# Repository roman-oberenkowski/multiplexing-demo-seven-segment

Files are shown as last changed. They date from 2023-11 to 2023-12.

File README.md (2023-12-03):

# Multiplexing demo - 7 segment display
Attiny2313 based educational tool to explain multiplexing effect of seven segment display by slowing down the process.
+ Precompilled HEX file available in 'releases'.
+ Schematic and Kicad project inside 'Schematic' directory.
+ Makefile inside Release directory (Note: built using NixOS, remove/change the compile workaround in Makefile if needed). Makefile generated by Eclipse and AVR plugin.
+ Press (or hold) up/down buttons to increase/decrease refresh frequency (between 1 and 64 Hz).
+ After change display shows current refresh frequency for some time.
+ Power by 9V battery or directly connect 5V to MicroUSB port.
+ Third and fourth digits are flipped to use dots as separator.
+ Includes 3D printable case for 5x7cm prototype boards.
+ Video demo: [Link](https://mega.nz/file/VVUVSJKa#2tisywkgibCrWytnNKbrjdRLIr3S0MkWB7HTtdX4rLc) (Warning: Flashing lights)
## Pics
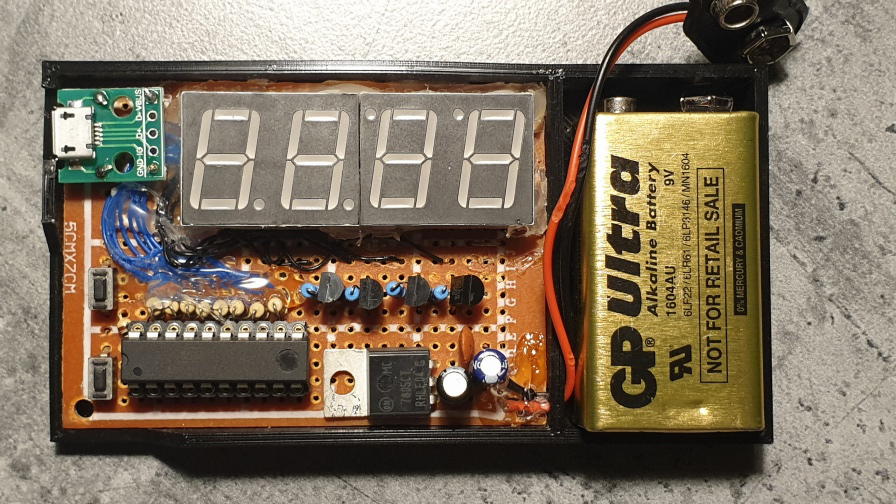
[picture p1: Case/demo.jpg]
demo

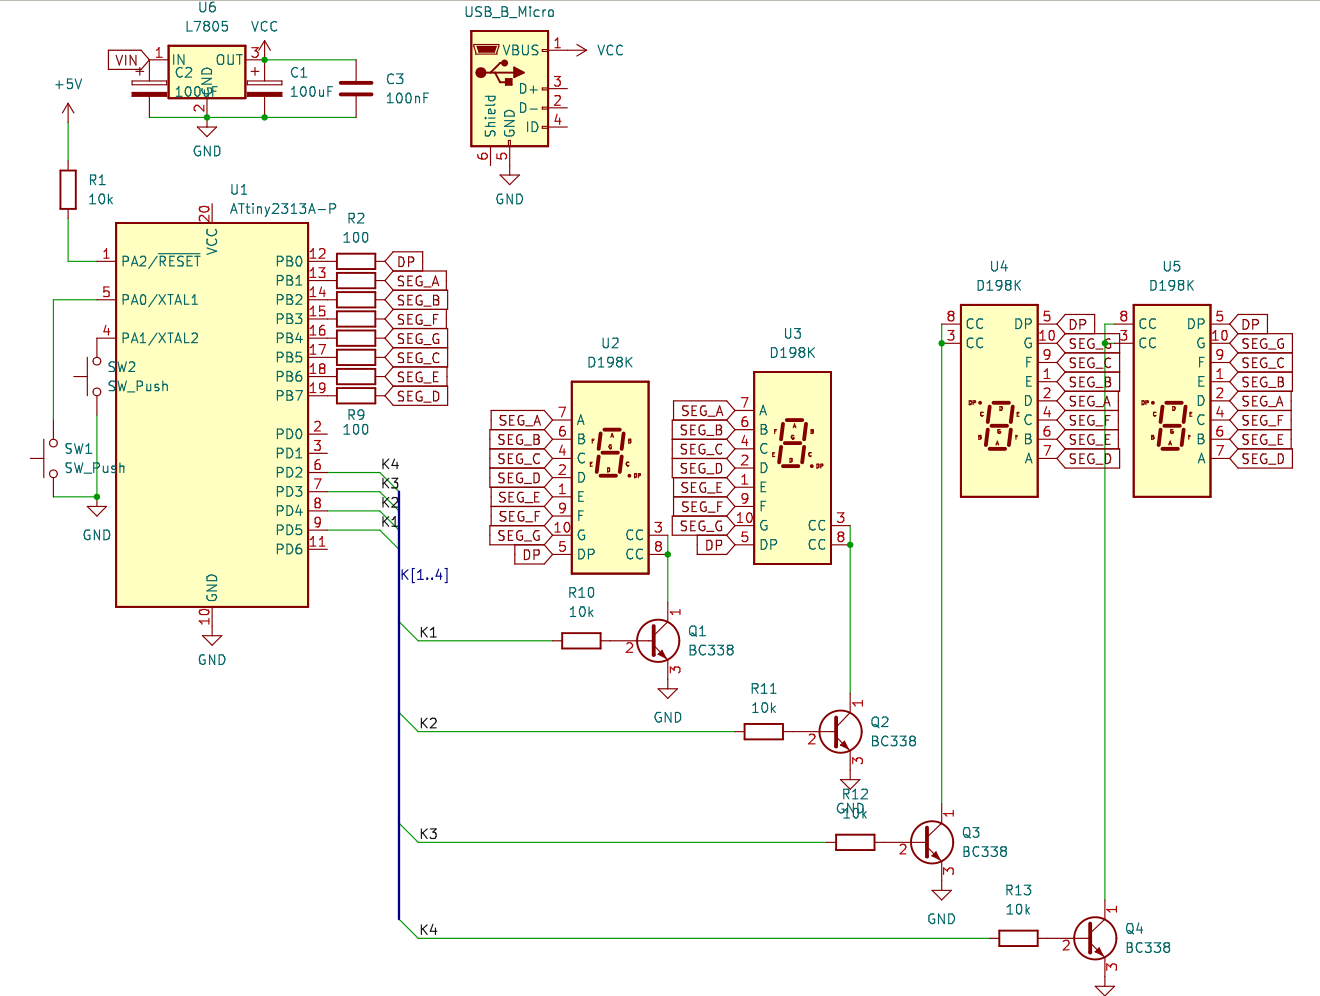
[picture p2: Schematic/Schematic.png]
schematic


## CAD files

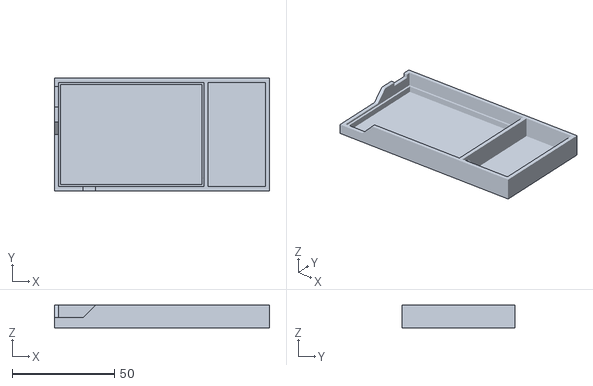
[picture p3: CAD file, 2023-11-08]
Case/7SegMultiDemoCase v1.stl
105.0 x 55.0 x 11.0

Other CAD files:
Case/7SegMultiDemoCase v1.f3d

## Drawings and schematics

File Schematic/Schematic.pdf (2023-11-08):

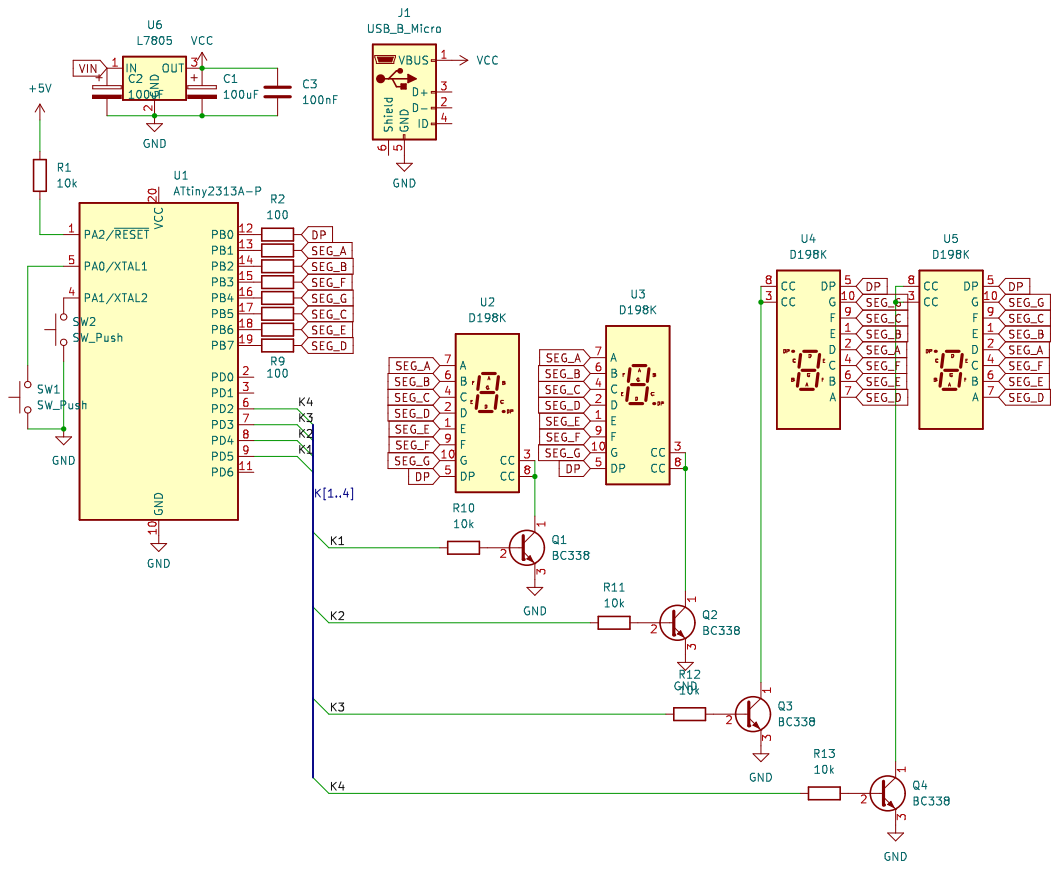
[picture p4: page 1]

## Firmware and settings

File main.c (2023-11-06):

/*
 * main.c
 *
 *  Created on: 26.07.2016
 *      Author: Unknown
 */
#include <avr/io.h>
#include <avr/interrupt.h>
#include "d_led.h"
#include <util/delay.h>

volatile uint8_t sec=0;
volatile uint8_t sec2=0;
volatile uint8_t min=0;
volatile uint8_t min2=0;
volatile uint8_t updateDisplayFlag=1;

void showTimer();
void makeRefreshSlowerAndShowHz();
void makeRefreshFasterAndShowHz();


/*
	number - one to show
	msToWait - delay to wait - in miliseconds (with granularity to 100ms, rounded down)
*/
void showNumberAndWait(uint16_t number, uint16_t msToWait){
	updateDisplayFlag=0;
	pos4 = DigitMap[number % 10];
	number /=10;
	pos3 = DigitMap[number % 10];
	number /=10;
	pos2 = 0x00; //DigitMap[number % 10];
	number /=10;
	pos1 = DigitMap[number % 10];
	for (uint8_t i = 0; i<msToWait/100; i++){
		_delay_ms(100);
	}
	showTimer();
	updateDisplayFlag=1;
}



int main(void){
	TCCR1B |= (1<<CS12);
	TCCR1B |= (1<<WGM12);
	TIMSK |= (1<<OCIE1A);
	OCR1A = 5000;	 	// 31250 for 1second
	d_led_init(); 		// setup pins, timer0 and interrupt for refresh operation
	
	DDRA &= ~((1<<PA0)| (1<<PA1)); 	// Buttons: DDR
	PORTA |= (1<<PA0)| (1<<PA1);	// Buttons: PULLUP
	pos1=DIGIT_8;
	pos2=DIGIT_7;
	pos3=DIGIT_6;
	pos4=DIGIT_5;
	sei();
	while(1){
		if( bit_is_clear(PINA, PA1) ){makeRefreshSlowerAndShowHz();}
		if( bit_is_clear(PINA, PA0) ){makeRefreshFasterAndShowHz();}
	}
}

void makeRefreshSlowerAndShowHz() {
	uint8_t currentHz = makeRefreshSlower();
	showNumberAndWait(currentHz, 200);
}
void makeRefreshFasterAndShowHz() {
	uint8_t currentHz = makeRefreshFaster();
	showNumberAndWait(currentHz, 200);
}

ISR(TIMER1_COMPA_vect){
	sec++;
	if(sec>9){sec=0;sec2++;}
	if(sec2>5){sec2=0;min++;}
	if(min>9){min=0;min2++;}
	if(min2>6){min2=0;}
	if (updateDisplayFlag){
		showTimer();
	}
}

void showTimer(){
	pos1=DigitMap[min2];
	pos2=DigitMap[min] | SEG_DOT;
	pos3=DigitMap[sec2] | SEG_DOT;
	pos4=DigitMap[sec];
}

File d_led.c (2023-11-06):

#include <avr/io.h>
#include <avr/interrupt.h>
#include "d_led.h"

volatile uint8_t pos1;
volatile uint8_t pos2;
volatile uint8_t pos3;
volatile uint8_t pos4;
uint8_t refreshHz=50;

volatile uint8_t additionalSoftwarePrescallerMax=0;
uint8_t DigitMap[10] = {DIGIT_0, DIGIT_1, DIGIT_2, DIGIT_3, DIGIT_4, DIGIT_5, DIGIT_6, DIGIT_7, DIGIT_8, DIGIT_9};
void d_led_init(void){
	DDRB = 0xFF;	// PORTB pin is used for each display segment
	DDRD |= LED_KK; // PORTD is used for all four cathodes (one per digit)
	TCCR0A |= (1<<WGM01); 	// TIMER0 (8bit), WGM01 => CTC
	TCCR0B |= (1<<CS02); 	// CS02 => CLK/256
	OCR0A = 155;		 	// OCR0A=155 => Timer/156 => 200Hz interrupt
	TIMSK |=(1<<OCIE0A);	// Enable Timer compare interrupt
}

void calculateAndSetTimings(){
	
	uint16_t ocrDivider = 8000000/256/refreshHz/4;
	if (ocrDivider<=255){
		TCCR0B &= ~(1<<CS00); // restore to /256
		OCR0A = ocrDivider-1; // TODO: check if zero, or underflow?
		additionalSoftwarePrescallerMax=0; // not used
	} else {
		ocrDivider /= 4;
		TCCR0B |= (1<<CS00); // set to /1024
		if (ocrDivider <= 255) {
			OCR0A = ocrDivider-1;
			additionalSoftwarePrescallerMax=0; // not used
		} else {
			additionalSoftwarePrescallerMax = 0;
			while (ocrDivider>255) {
				ocrDivider /= 2;
				additionalSoftwarePrescallerMax++;
			}
		}
	}
}

uint8_t makeRefreshSlower(){
	refreshHz = (refreshHz-1) % 64;
	if (refreshHz==0) {
		refreshHz=1;
	}
	calculateAndSetTimings();
	return refreshHz;
}

uint8_t makeRefreshFaster() {
	refreshHz = (refreshHz+1) % 64;
	if (refreshHz==0) {
		refreshHz=63;
	}
	calculateAndSetTimings();
	return refreshHz;
}

	
ISR(TIMER0_COMPA_vect){ // Show (refresh) the digit on the next position
	static uint8_t currentPosition = 0;
	static uint8_t additionalSoftwarePrescallerCurrent = 0;
	if (additionalSoftwarePrescallerMax > 0 && additionalSoftwarePrescallerCurrent++ < additionalSoftwarePrescallerMax ) {
		return;
	}
	additionalSoftwarePrescallerCurrent=0;

	//PORTD &= ~LED_KK; // disable all cathodes (current one) to prevent ghosting
	PORTB = 0x00; // disable all segments to prevent ghosting

	switch (currentPosition) {
		case 0:
			PORTD = LED_K1; // enable cathode
			PORTB = pos1;	// enable correct output (order is important to prevent ghosting)
			break;
		case 1:
			PORTD = LED_K2;
			PORTB = pos2;
			break;
		case 2:
			PORTD = LED_K3;
			PORTB = pos3;
			break;
		case 3:
			PORTD = LED_K4;
			PORTB = pos4;
			break;
	}
	currentPosition = (currentPosition + 1) & 0b0011; // increment and mask to get 0..3 range
}
